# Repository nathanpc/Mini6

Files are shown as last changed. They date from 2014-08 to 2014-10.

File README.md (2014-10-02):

# Mini6

A mini 3 watts per channel amplifier.

PCB Layout

## Schematic

It's a very simple amplifier with a op-amp based pre-amp and buffered volume control followed by a small power amplifier with a [CFP output stage](http://en.wikipedia.org/wiki/Sziklai_pair).

Schematic

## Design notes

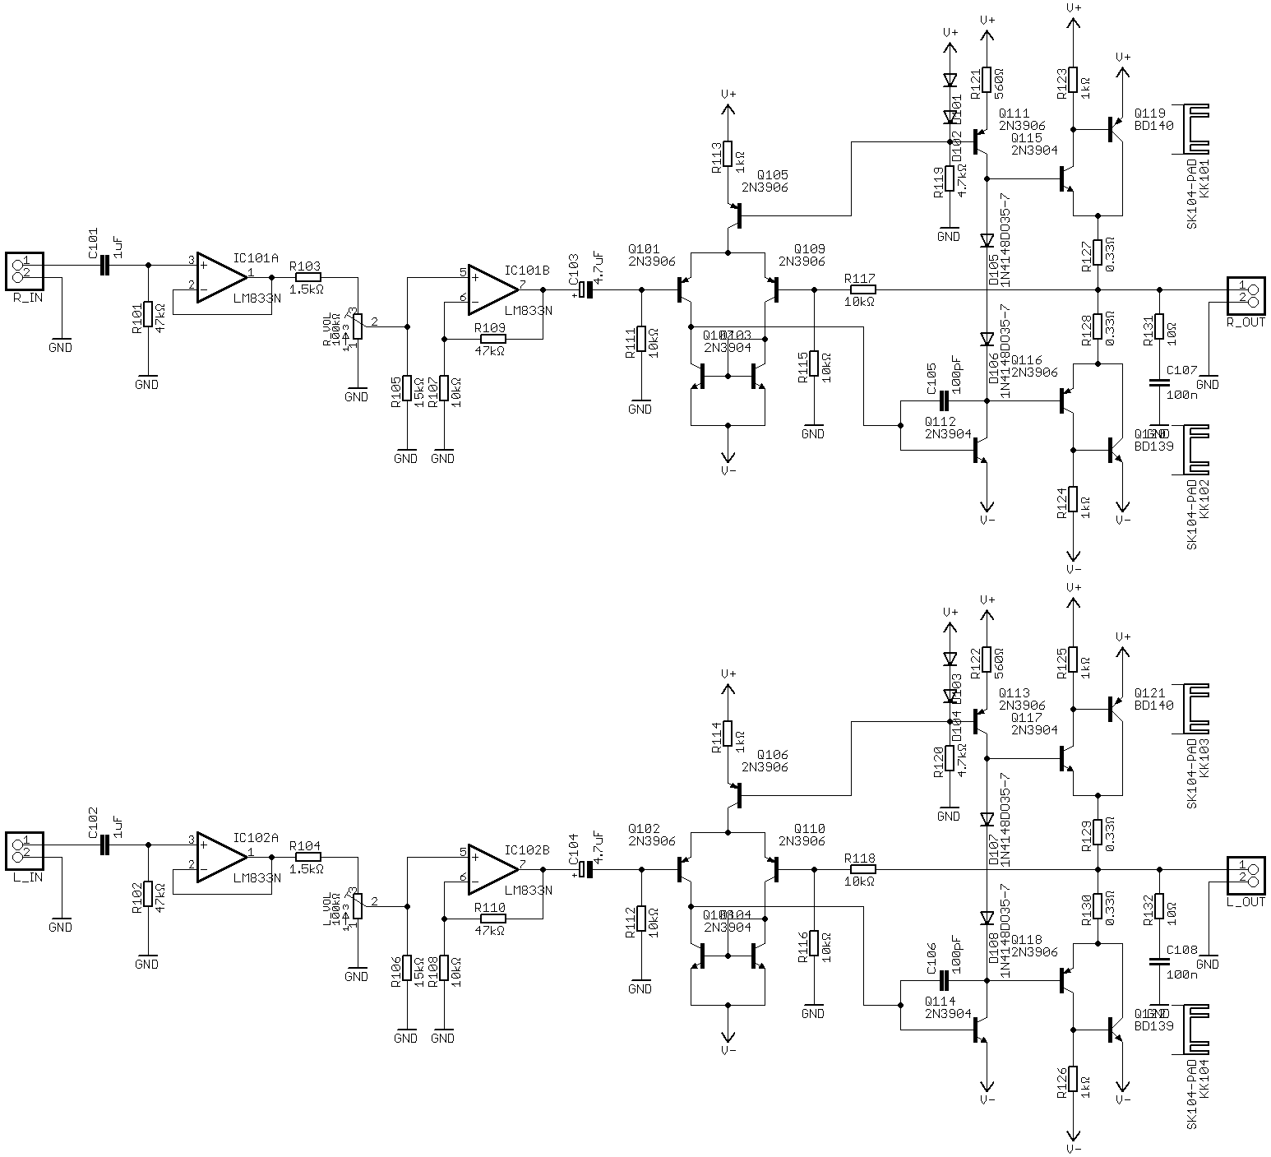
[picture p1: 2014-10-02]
images/Amplifier (Rev B).png

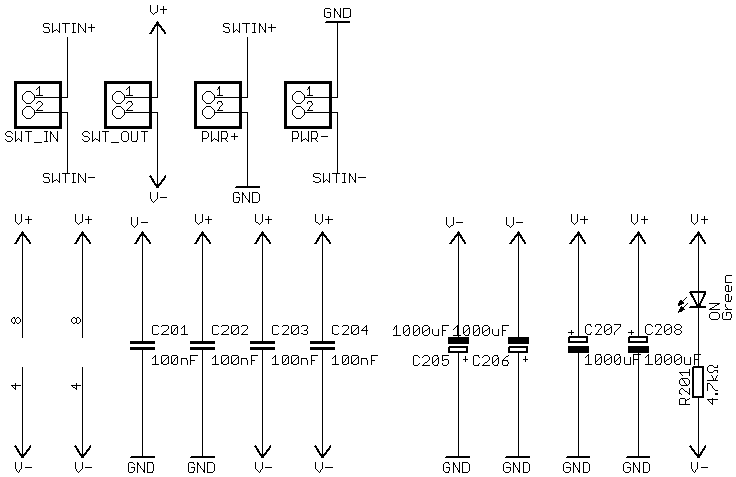
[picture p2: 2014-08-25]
images/Power Supply.png

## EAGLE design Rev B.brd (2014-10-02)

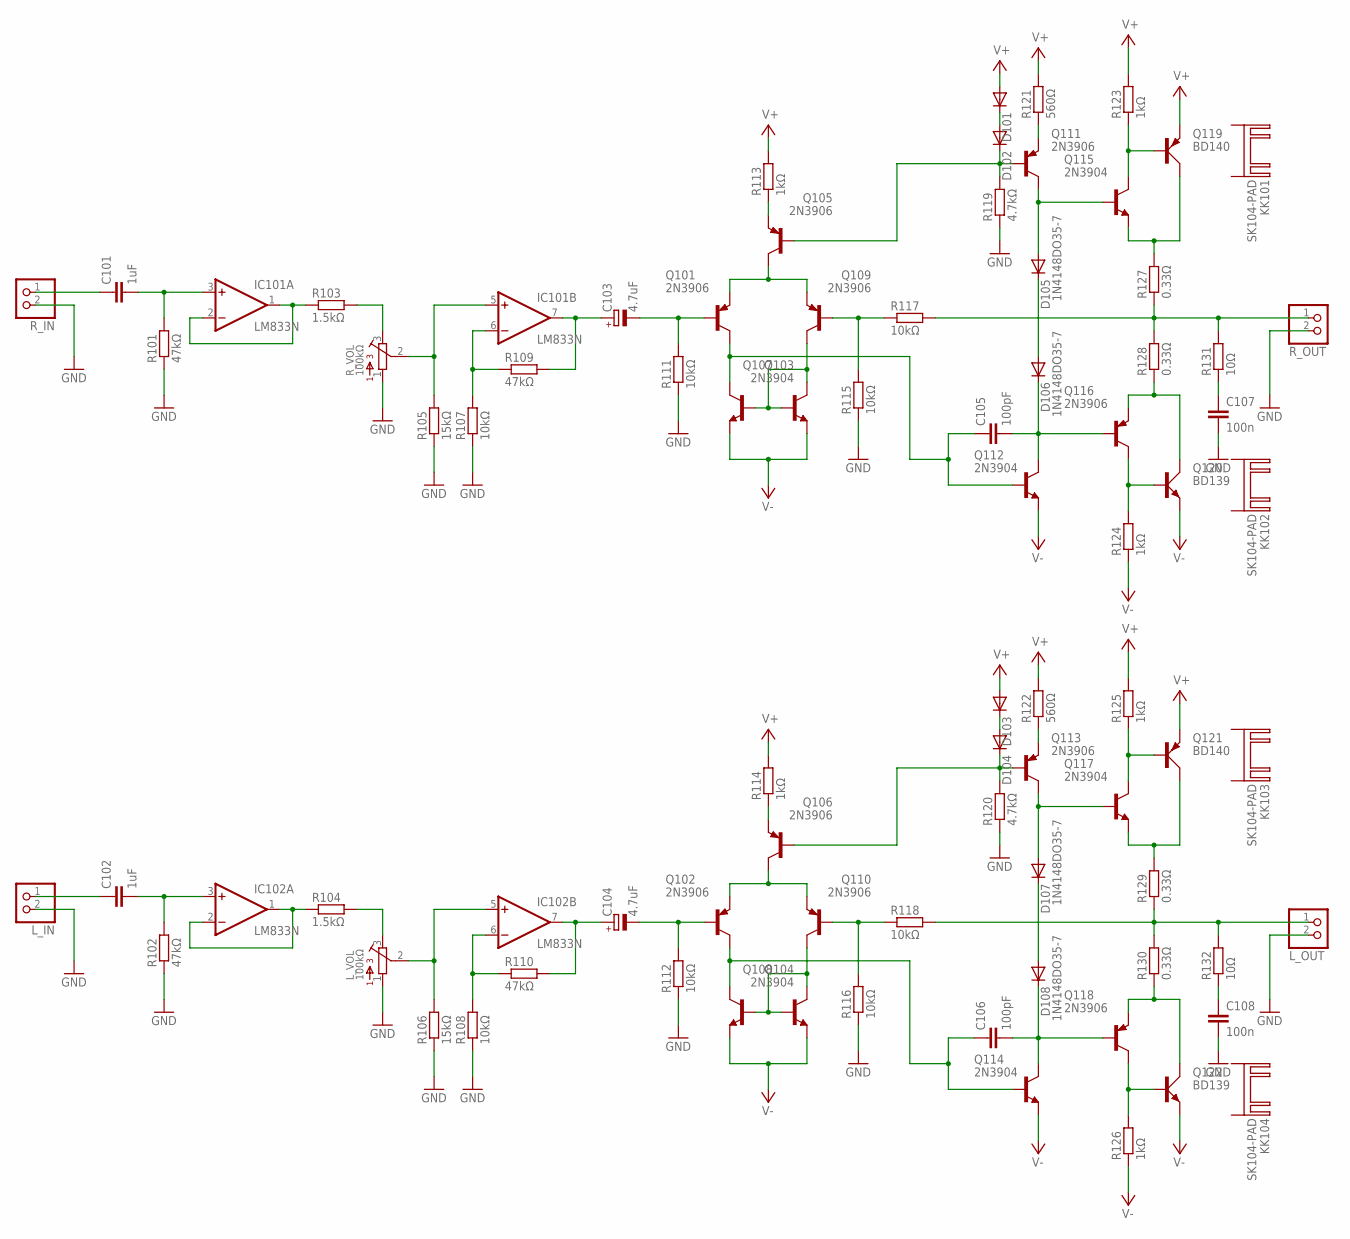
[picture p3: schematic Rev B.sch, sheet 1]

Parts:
C101, C102: 1uF; C150-072X183
C103, C104: 4.7uF; E2-5
C105, C106: 100pF; C050-050X075
C107, C108: 100n; C075-042X103
D101, D102, D103, D104, D105, D106, D107, D108: 1N4148DO35-7; DO35-7
IC101, IC102: LM833N; DIL08
KK101, KK102, KK103, KK104: SK104-PAD
L_IN: JST_2PIN-THM; JST-PH-2-THM
L_OUT: JST_2PIN-THM; JST-PH-2-THM
L_VOL: 100kΩ; 3362U
Q101, Q102, Q105, Q106, Q109, Q110, Q111, Q113, Q116, Q118: 2N3906; TO92
Q103, Q104, Q107, Q108, Q112, Q114, Q115, Q117: 2N3904; TO92
Q119, Q121: BD140; TO126AV
Q120, Q122: BD139; TO126AV
R101, R102, R109, R110: 47kΩ; 0207/10
R103, R104: 1.5kΩ; 0207/10
R105, R106: 15kΩ; 0207/10
R107, R108, R111, R112, R115, R116, R117, R118: 10kΩ; 0207/10
R113, R114, R123, R124, R125, R126: 1kΩ; 0207/10
R119, R120: 4.7kΩ; 0207/10
R121, R122: 560Ω; 0207/10
R127, R128, R129, R130: 0.33Ω; 0309/12
R131, R132: 10Ω; 0617V
R_IN: JST_2PIN-THM; JST-PH-2-THM
R_OUT: JST_2PIN-THM; JST-PH-2-THM
R_VOL: 100kΩ; 3362U

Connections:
GND: C107.2, C108.2, L_IN.2 (1), L_OUT.2 (1), L_VOL.1, R101.1, R102.1, R105.1, R106.1, R107.1, R108.1, R111.1, R112.1, R115.1, R116.1, R119.1, R120.1, R_IN.2 (1), R_OUT.2 (1), R_VOL.1; also elsewhere on the board
L_OUT: L_OUT.1 (2), R118.2, R129.1, R130.2, R132.2
unnamed: D105.A, Q111.1 (C), Q115.2 (B)
unnamed: Q101.3 (E), Q105.1 (C), Q109.3 (E)
unnamed: Q103.2 (B), Q107.1 (C), Q107.2 (B), Q109.1 (C)
unnamed: Q104.2 (B), Q108.1 (C), Q108.2 (B), Q110.1 (C)
unnamed: C103.-, Q101.2 (B), R111.2
unnamed: C103.+, IC101.7 (OUT), R109.2
unnamed: C101.1, R_IN.1 (2)
unnamed: C105.1, Q101.1 (C), Q103.1 (C), Q112.2 (B)
unnamed: C101.2, IC101.3 (+IN), R101.2
unnamed: IC102.1 (OUT), IC102.2 (-IN), R104.1
unnamed: IC102.5 (+IN), L_VOL.2, R106.2
unnamed: L_VOL.3, R104.2
unnamed: IC102.6 (-IN), R108.2, R110.1
unnamed: C102.1, L_IN.1 (2)
unnamed: C102.2, IC102.3 (+IN), R102.2
unnamed: Q105.3 (E), R113.1
unnamed: Q111.3 (E), R121.1
unnamed: D102.C, Q105.2 (B), Q111.2 (B), R119.2
unnamed: D101.C, D102.A
unnamed: C107.1, R131.1
unnamed: C108.1, R132.1
unnamed: Q106.3 (E), R114.1
unnamed: D105.C, D106.A
unnamed: C104.-, Q102.2 (B), R112.2
unnamed: Q115.1 (C), Q119.B, R123.1
unnamed: Q116.1 (C), Q120.B, R124.2
unnamed: Q116.3 (E), Q120.C, R128.1
unnamed: Q115.3 (E), Q119.C, R127.2
unnamed: C104.+, IC102.7 (OUT), R110.2
unnamed: C105.2, D106.C, Q112.1 (C), Q116.2 (B)
unnamed: Q109.2 (B), R115.2, R117.1
unnamed: Q102.3 (E), Q106.1 (C), Q110.3 (E)
unnamed: C106.1, Q102.1 (C), Q104.1 (C), Q114.2 (B)
unnamed: D107.C, D108.A
unnamed: D107.A, Q113.1 (C), Q117.2 (B)
unnamed: Q117.1 (C), Q121.B, R125.1
unnamed: Q117.3 (E), Q121.C, R129.2
unnamed: Q118.1 (C), Q122.B, R126.2
unnamed: Q118.3 (E), Q122.C, R130.1
unnamed: C106.2, D108.C, Q114.1 (C), Q118.2 (B)
unnamed: Q110.2 (B), R116.2, R118.1
unnamed: Q113.3 (E), R122.1
unnamed: D104.C, Q106.2 (B), Q113.2 (B), R120.2
unnamed: D103.C, D104.A
unnamed: IC101.1 (OUT), IC101.2 (-IN), R103.1
unnamed: IC101.5 (+IN), R105.2, R_VOL.2
unnamed: R103.2, R_VOL.3
unnamed: IC101.6 (-IN), R107.2, R109.1
R_OUT: R117.2, R127.1, R128.2, R131.2, R_OUT.1 (2)
V+: D101.A, D103.A, Q119.E, Q121.E, R113.2, R114.2, R121.2, R122.2, R123.2, R125.2; also elsewhere on the board
V-: Q103.3 (E), Q104.3 (E), Q107.3 (E), Q108.3 (E), Q112.3 (E), Q114.3 (E), Q120.E, Q122.E, R124.1, R126.1; also elsewhere on the board

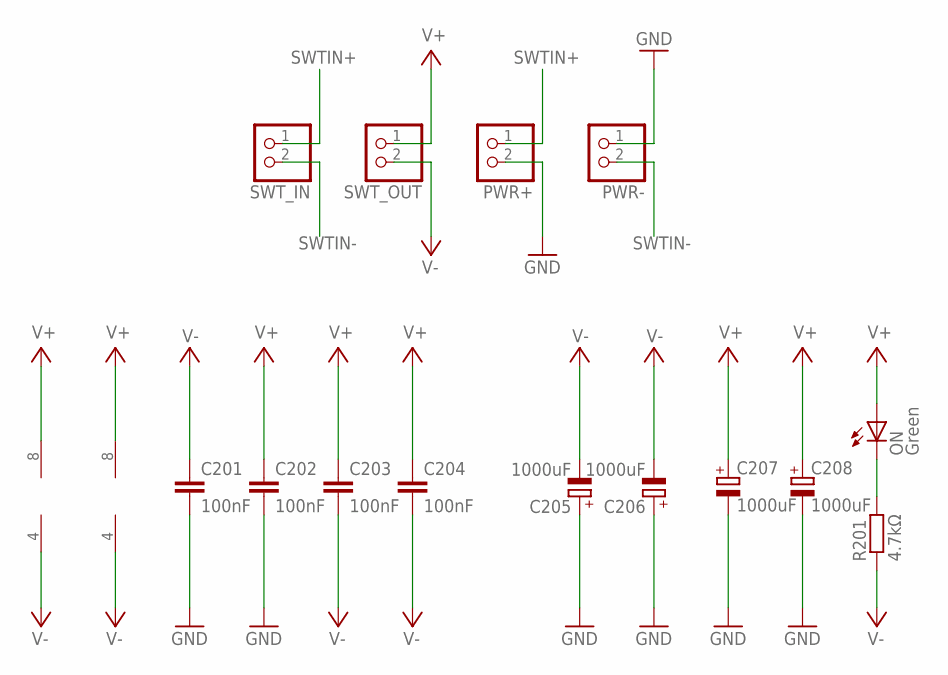
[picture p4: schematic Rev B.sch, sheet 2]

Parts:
C201, C202, C203, C204: 100nF; C025-025X050
C205, C206, C207, C208: 1000uF; E5-10,5
IC101, IC102: LM833N; DIL08
ON: Green; LED5MM
PWR+: JST_2PIN-THM; JST-PH-2-THM
PWR-: JST_2PIN-THM; JST-PH-2-THM
R201: 4.7kΩ; 0207/10
SWT_IN: JST_2PIN-THM; JST-PH-2-THM
SWT_OUT: JST_2PIN-THM; JST-PH-2-THM

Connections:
GND: C201.2, C202.2, C205.+, C206.+, C207.-, C208.-, PWR+.2 (1), PWR-.1 (2); also elsewhere on the board
unnamed: ON.K (C), R201.2
SWTIN+: PWR+.1 (2), SWT_IN.1 (2)
SWTIN-: PWR-.2 (1), SWT_IN.2 (1)
V+: C202.1, C203.1, C204.1, C207.+, C208.+, IC101.8 (V+), IC102.8 (V+), ON.A, SWT_OUT.1 (2); also elsewhere on the board
V-: C201.1, C203.2, C204.2, C205.-, C206.-, IC101.4 (V-), IC102.4 (V-), R201.1, SWT_OUT.2 (1); also elsewhere on the board

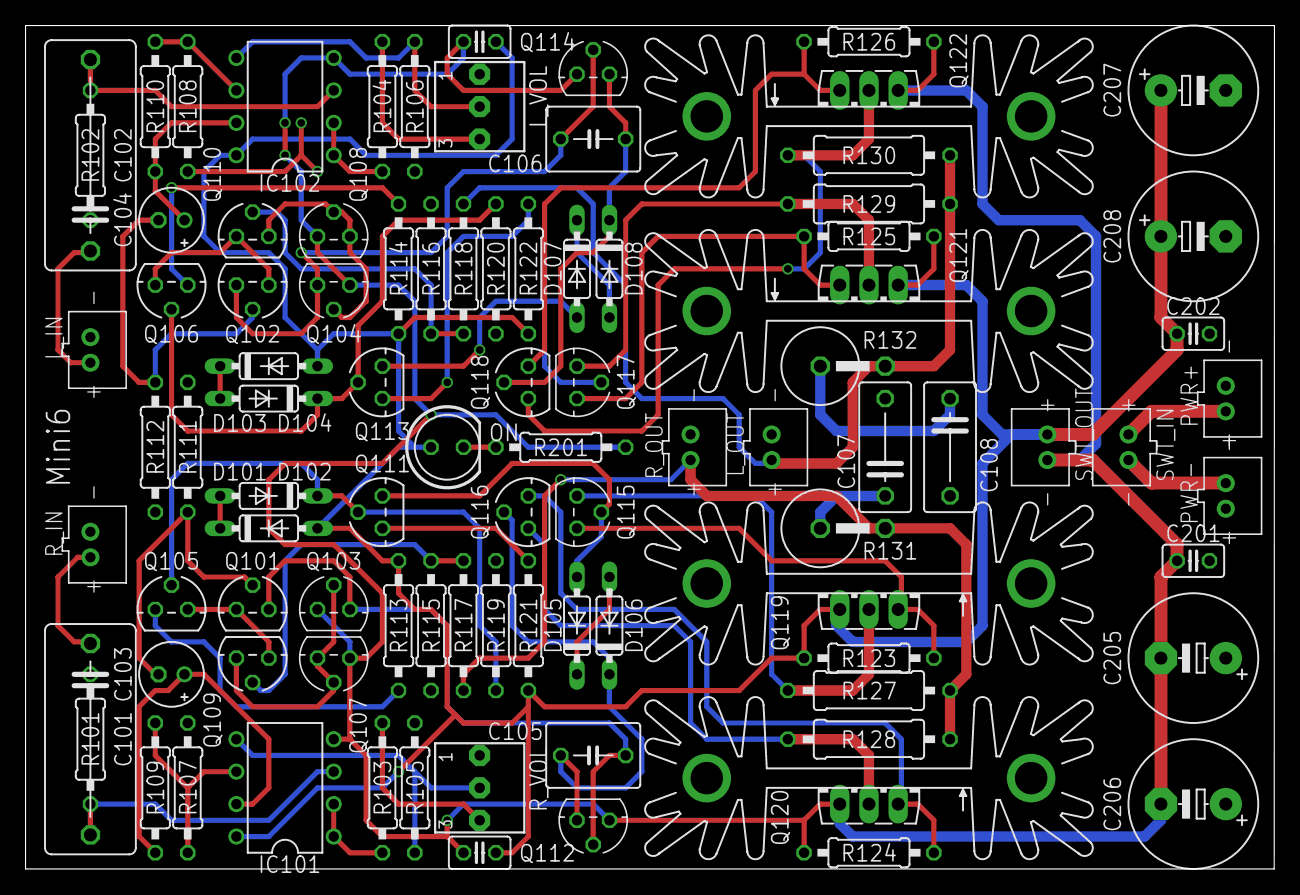
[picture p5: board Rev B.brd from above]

Board: 4 copper layers, 97.8 x 66.0 mm, 96 parts (0 on the bottom side), 56 nets.

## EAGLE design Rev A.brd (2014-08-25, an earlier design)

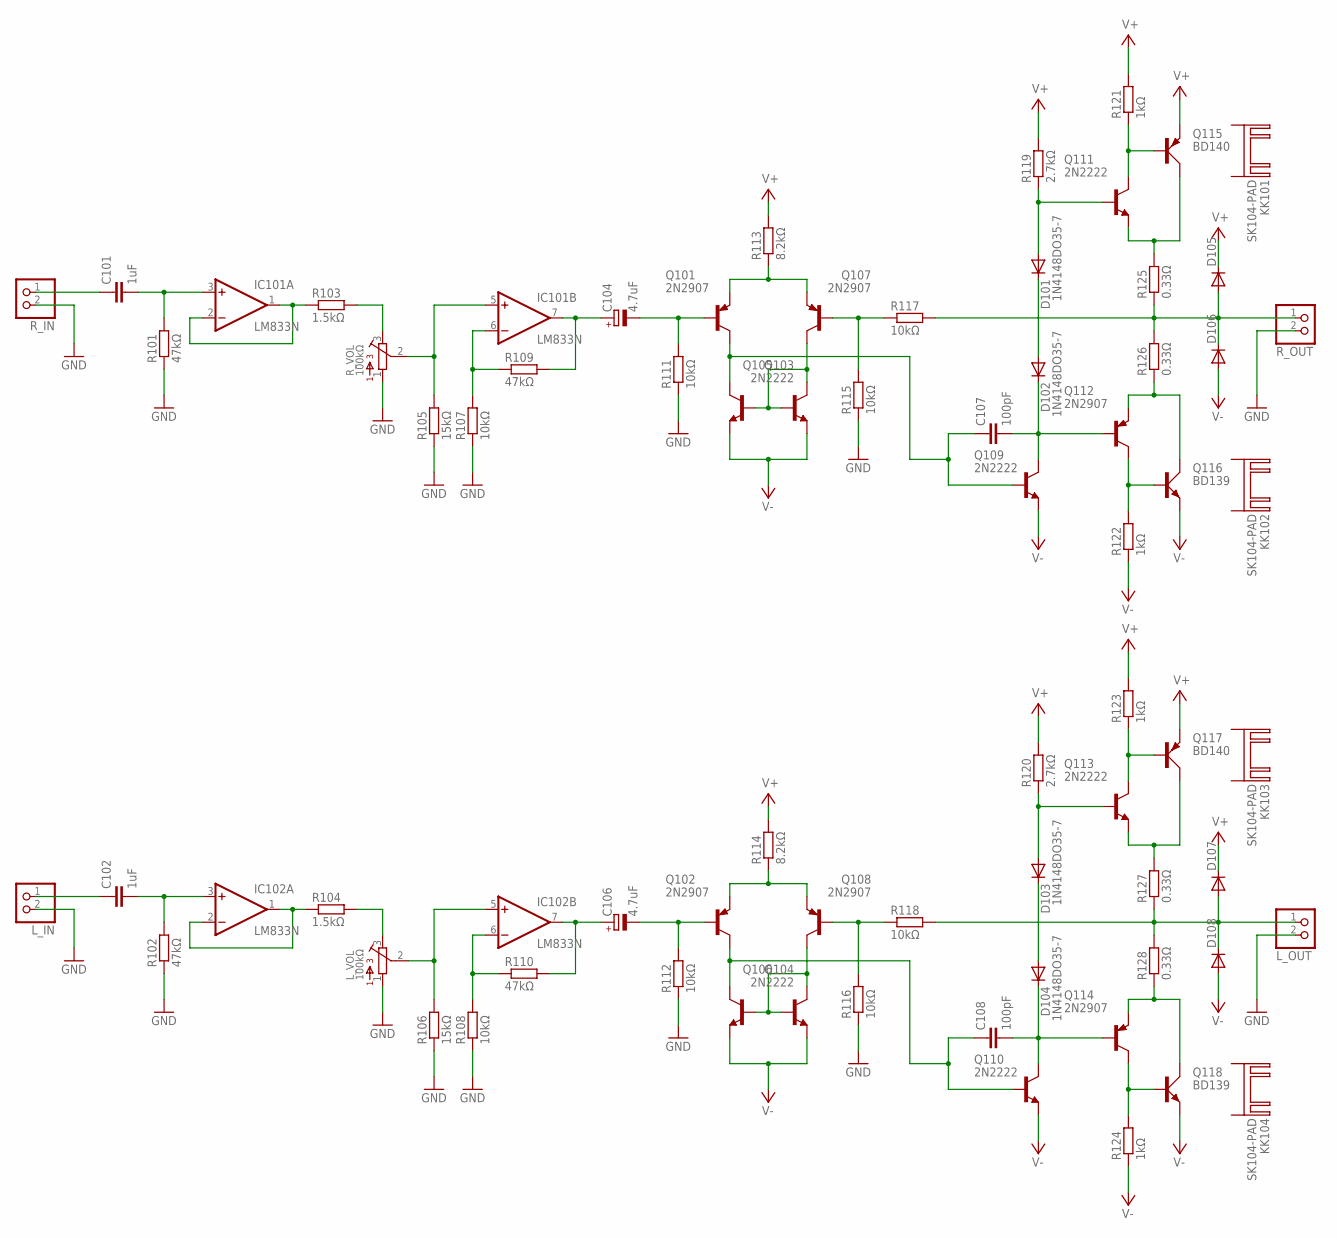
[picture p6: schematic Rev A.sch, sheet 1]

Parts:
C101, C102: 1uF; C050-050X075
C104, C106: 4.7uF; E2-5
C107, C108: 100pF; C050-050X075
D101, D102, D103, D104, D105, D106, D107, D108: 1N4148DO35-7; DO35-7
IC101, IC102: LM833N; DIL08
KK101, KK102, KK103, KK104: SK104-PAD
L_IN: JST_2PIN-THM; JST-PH-2-THM
L_OUT: JST_2PIN-THM; JST-PH-2-THM
L_VOL: 100kΩ; 3362U
Q101, Q102, Q107, Q108, Q112, Q114: 2N2907; TO18
Q103, Q104, Q105, Q106, Q109, Q110, Q111, Q113: 2N2222; TO18
Q115, Q117: BD140; TO126AV
Q116, Q118: BD139; TO126AV
R101, R102, R109, R110: 47kΩ; 0207/10
R103, R104: 1.5kΩ; 0207/10
R105, R106: 15kΩ; 0207/10
R107, R108, R111, R112, R115, R116, R117, R118: 10kΩ; 0207/10
R113, R114: 8.2kΩ; 0207/10
R119, R120: 2.7kΩ; 0207/10
R121, R122, R123, R124: 1kΩ; 0207/10
R125, R126, R127, R128: 0.33Ω; 0309/12
R_IN: JST_2PIN-THM; JST-PH-2-THM
R_OUT: JST_2PIN-THM; JST-PH-2-THM
R_VOL: 100kΩ; 3362U

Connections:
GND: L_IN.2 (1), L_OUT.2 (1), L_VOL.1, R101.1, R102.1, R105.1, R106.1, R107.1, R108.1, R111.1, R112.1, R115.1, R116.1, R_IN.2 (1), R_OUT.2 (1), R_VOL.1; also elsewhere on the board
L_OUT: D107.A, D108.C, L_OUT.1 (2), R118.2, R127.1, R128.2
unnamed: D101.A, Q111.2 (B), R119.1
unnamed: Q101.1 (E), Q107.1 (E), R113.1
unnamed: Q103.2 (B), Q105.2 (B), Q105.3 (C), Q107.3 (C)
unnamed: Q104.2 (B), Q106.2 (B), Q106.3 (C), Q108.3 (C)
unnamed: C104.-, Q101.2 (B), R111.2
unnamed: C104.+, IC101.7 (OUT), R109.2
unnamed: C101.1, R_IN.1 (2)
unnamed: C107.1, Q101.3 (C), Q103.3 (C), Q109.2 (B)
unnamed: C101.2, IC101.3 (+IN), R101.2
unnamed: IC102.1 (OUT), IC102.2 (-IN), R104.1
unnamed: IC102.5 (+IN), L_VOL.2, R106.2
unnamed: L_VOL.3, R104.2
unnamed: IC102.6 (-IN), R108.2, R110.1
unnamed: C102.1, L_IN.1 (2)
unnamed: C102.2, IC102.3 (+IN), R102.2
unnamed: D101.C, D102.A
unnamed: C106.-, Q102.2 (B), R112.2
unnamed: Q111.3 (C), Q115.B, R121.1
unnamed: Q112.3 (C), Q116.B, R122.2
unnamed: Q112.1 (E), Q116.C, R126.1
unnamed: Q111.1 (E), Q115.C, R125.2
unnamed: C106.+, IC102.7 (OUT), R110.2
unnamed: C107.2, D102.C, Q109.3 (C), Q112.2 (B)
unnamed: Q107.2 (B), R115.2, R117.1
unnamed: Q102.1 (E), Q108.1 (E), R114.1
unnamed: C108.1, Q102.3 (C), Q104.3 (C), Q110.2 (B)
unnamed: D103.C, D104.A
unnamed: D103.A, Q113.2 (B), R120.1
unnamed: Q113.3 (C), Q117.B, R123.1
unnamed: Q113.1 (E), Q117.C, R127.2
unnamed: Q114.3 (C), Q118.B, R124.2
unnamed: Q114.1 (E), Q118.C, R128.1
unnamed: C108.2, D104.C, Q110.3 (C), Q114.2 (B)
unnamed: Q108.2 (B), R116.2, R118.1
unnamed: IC101.1 (OUT), IC101.2 (-IN), R103.1
unnamed: IC101.5 (+IN), R105.2, R_VOL.2
unnamed: R103.2, R_VOL.3
unnamed: IC101.6 (-IN), R107.2, R109.1
R_OUT: D105.A, D106.C, R117.2, R125.1, R126.2, R_OUT.1 (2)
V+: D105.C, D107.C, Q115.E, Q117.E, R113.2, R114.2, R119.2, R120.2, R121.2, R123.2; also elsewhere on the board
V-: D106.A, D108.A, Q103.1 (E), Q104.1 (E), Q105.1 (E), Q106.1 (E), Q109.1 (E), Q110.1 (E), Q116.E, Q118.E, R122.1, R124.1; also elsewhere on the board

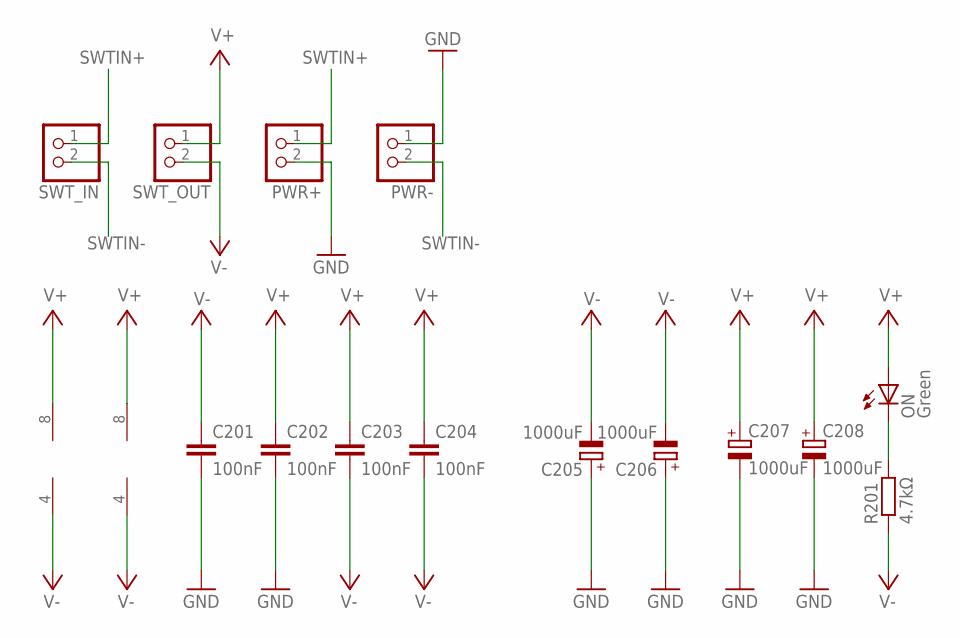
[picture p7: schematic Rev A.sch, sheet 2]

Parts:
C201, C202, C203, C204: 100nF; C025-025X050
C205, C206, C207, C208: 1000uF; E5-10,5
IC101, IC102: LM833N; DIL08
ON: Green; LED5MM
PWR+: JST_2PIN-THM; JST-PH-2-THM
PWR-: JST_2PIN-THM; JST-PH-2-THM
R201: 4.7kΩ; 0207/10
SWT_IN: JST_2PIN-THM; JST-PH-2-THM
SWT_OUT: JST_2PIN-THM; JST-PH-2-THM

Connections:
GND: C201.2, C202.2, C205.+, C206.+, C207.-, C208.-, PWR+.2 (1), PWR-.1 (2); also elsewhere on the board
unnamed: ON.K (C), R201.2
SWTIN+: PWR+.1 (2), SWT_IN.1 (2)
SWTIN-: PWR-.2 (1), SWT_IN.2 (1)
V+: C202.1, C203.1, C204.1, C207.+, C208.+, IC101.8 (V+), IC102.8 (V+), ON.A, SWT_OUT.1 (2); also elsewhere on the board
V-: C201.1, C203.2, C204.2, C205.-, C206.-, IC101.4 (V-), IC102.4 (V-), R201.1, SWT_OUT.2 (1); also elsewhere on the board

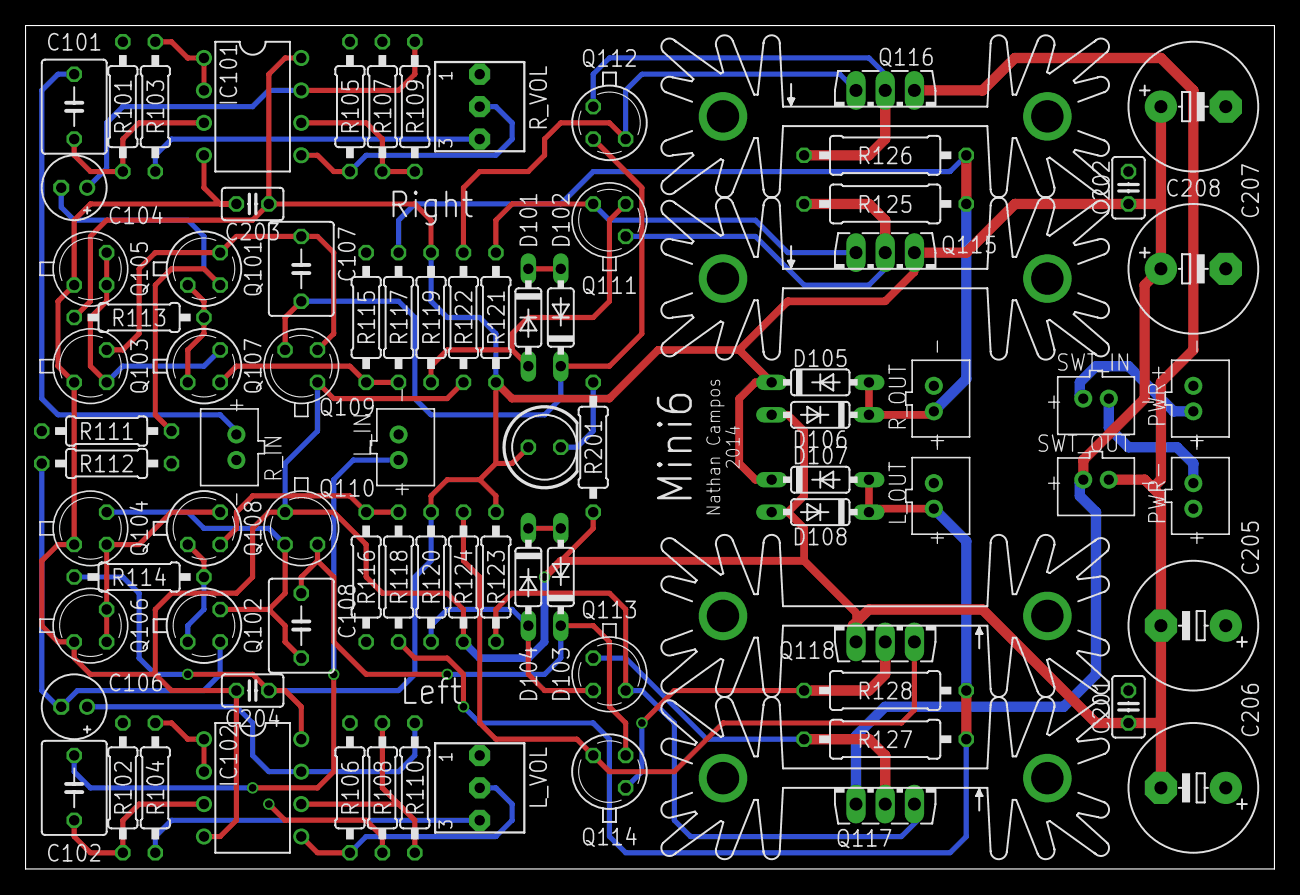
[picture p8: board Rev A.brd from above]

Board: 4 copper layers, 97.8 x 66.0 mm, 86 parts (0 on the bottom side), 46 nets.

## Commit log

2014-08-24 First draft of the schematic
    [Rev A.sch]
2014-08-24 Replaced all the low-power transistors with TO-18 versions
    [Rev A.sch]
2014-08-25 Ready for production
    [Rev A.brd, Rev A.sch]
2014-08-25 Exported the schematic and board layout
2014-10-02 Rev B
    [Rev B.brd, Rev B.sch]
